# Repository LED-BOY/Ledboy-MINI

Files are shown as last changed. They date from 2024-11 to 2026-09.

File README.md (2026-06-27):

# Ledboy-MINI
Ledboy  mini game console and watch, plus a attiny 416 dev board.

Features: 

-128x32 sd1306 oled screen

-Batt charger IC

-Buzzer

-Sensor

-4k 20mhz MCU

-USB to serial CH340E

-Button input

-Micro USB port

-RGB LED

-RTC clock

-Temp. monitor

-Mosfet controlled batt ouput.




# Ledboy MINI schematics 

[Ledboy mini 1.4 rev b schematic.pdf](https://github.com/user-attachments/files/17895039/Ledboy.mini.1.4.rev.b.schematic.pdf)

# Board Layout

PCB layout

# Assembly guide

[Ledboy mini quick assembly guide.pdf](https://github.com/user-attachments/files/18432793/Ledboy.mini.quick.assembly.guide.pdf)

# How to Flash:

NOTICE:
IF USING ONLY THE USB CABLE WITHOUT A BATTERY, HOW THE CHARGER IC IS CONFIGURED IT ONLY DELIVERS  100MHA, IT IS ENOUGHT FOR FLASHING TURNING ON THE MCU AND THE LED, BUT THE OLED SCREEN WILL NOT WORK PROPERLY.
ADD A BATTERY IF YOU INTEND TO USE THE OLED SCEEN WITH THE DEVICE, OR CHANGE THE R1 RESISTOR VALUE TO A 0603 2K OHM.

## Windows 10/11 tutorial:

*If you have Avrdudess working under linux or Mac, it also should work, CH340E drivers are required.

## Drivers:
Download CH341SER.EXE windows drivers from: https://www.wch-ic.com/products/CH340.html?

## Avrdudess method (recomended):

Download all apps and games precompiled from releases: https://github.com/LED-BOY/Ledboy-MINI/releases

Download Avrdudess: https://github.com/ZakKemble/AVRDUDESS

Make sure all your settings are the same:

The only thing it may be different is your COM port.
If you don't have any other serial device, the only com port available should be your Ledboy 2,
if not, unplug your Ledboy 2 and see what port is missing, then reconnect you Ledboy 2, that is yours Ledboy 2 COM port.
Make sure you select the .hex file in the Flash slot.

Arduboy Flash

## Flash from source:
To Flash from source and make changes to the code you need to install a few things.

1- Legacy arduino software 1.8.19 works well: https://www.arduino.cc/en/software

2- Follow instll instruction to add attiny boards to Arduino IDE: https://github.com/SpenceKonde/megaTinyCore

3- Istall Tiny i2c to librarys, needed to compile: https://github.com/technoblogy/tiny-i2c

Add the new library: tiny-i2c-master.zip

Sin título

Once you have all installed intro the Arduio IDE you can start configuring the board parameters.
Com port should be the one available when you connect your ledboy mini.

DON'T FORGET TO BURN BOOTLOADER BEFORE FLASHING IF USING THIS OPTION.

Arduino flashing

You can check if the program compiles using the check mark, keep in mind that this MCU only has 4096 bytes of flash.

compiling

To upload the program to your Ledboy Mini, click the right arrow.

# Assemble the screen and sensor if needed.
if you are using the lastest watch firmware is configured to have a 1uf capacitor between the sensor pin and GND.
If you dont want to solder the sensor you have to change the variable (constexpr uint8_t sensorSensitivity) to a much higher value like 8.

Ledboy 2 V1 4 REV B v2
You need to use a 4 pin header to solder the oled screen.

Photo for reference.


# Strap options

22mm recommended Hook & Loop Nylon Strap

[https://www.aliexpress.com/item/1005002060362335.html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](https://www.aliexpress.com/item/1005005994868690.html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)

Sin título

# The battery situation

battery

The recommended battery is: 302030 LIPO 3.7v 120mhs, it gives a nice battery duration, it fit nicely, and the batt charger IC is configured to charge at 100mha aprox.
Which is adequate for this battery capacity.

Make sure to be carfull when soldering the battery, do not short the contacts, is better to solder the positive first (red wire), then negative.

## Configure the charger IC

If you whant to add a bigger battery you can change the R1 resistor to a 0603 2k ohm, that will give you the max 500 mha that the charger is capable to deliver.

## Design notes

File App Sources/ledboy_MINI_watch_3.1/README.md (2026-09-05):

# LEDBOY MINI Watch 3.1

Improved ATtiny416 watch firmware. Version 3.0 remains unchanged in its own
folder.

## Reset confirmation

Selecting the reset icon now opens a confirmation screen with the reset icon
and a large number:

- `0` = cancel; do not reset the watch
- `1` = confirm; reset the watch

The screen starts at `0`. Press the button to toggle between `0` and `1`, then
leave it untouched for two seconds to accept the displayed choice. This uses the
same familiar interaction as the watch's other numeric options.

## Additional improvements

- Removed the misleading reset logo and 1.5-second delay shown on every normal
  startup. The watch now starts directly on its normal display.
- A button press used to dismiss a finished minute timer no longer also opens
  the options menu.
- Setting the minute timer to zero now fully resets its counters, LED, and sound
  output instead of only clearing its active flag.
- Added protection against division by zero if the ADC ever returns an invalid
  zero reading.
- Clears a pending RTC tick before re-enabling the RTC interrupt after setting
  the time, preventing an immediate unexpected one-second increment.
- Simplified the battery bar, LED color selector, option positioning, and digit
  drawing to recover enough flash for confirmation and improve maintainability.

## Verified build settings

- Board/core: ATtiny416 with megaTinyCore 2.6.10
- Clock: 5 MHz internal
- millis()/micros(): disabled
- `printf()`: **Default**
- Library: TinyI2C 2.0.1

The `printf: Minimal` setting must not be used for this firmware. The sketch
does not call `printf`, so the default implementation is removed by the linker.
Selecting Minimal forces its approximately 1.1 KB formatter into the image and
overflows the ATtiny416 flash.

Verified default-printf build:

- Flash: 3987 / 4096 bytes (97%)
- Global RAM: 26 / 256 bytes (10%)
- Remaining: 109 bytes flash and 230 bytes RAM for locals/stack

Use the same programmer, UPDI, BOD, and pinout settings as the working 3.0
release.

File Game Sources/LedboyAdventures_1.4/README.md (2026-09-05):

# LedboyAdventures 1.4

Advanced gameplay release for LEDBOY MINI / ATtiny416. Version 1.3 remains
unchanged in its own folder.

## New gameplay

- The dotted grass/ground texture has been removed for a cleaner playfield;
  the trees remain.
- Player, ground-enemy, flying-enemy, shield-orb, and shield-hit movement now
  explicitly erase the previous coordinates so no ghost trails remain.
- Two hazard heights:
  - Ground invaders are avoided with a normal jump and award 2 points.
  - Mirrored flying invaders occupy the middle row, can be cleared by a normal
    jump, and award 3 points.
- Enemy types change during the run instead of following one fixed pattern.
- Respawn positions vary between columns 112 and 119, creating less predictable
  obstacle spacing.
- Shield orbs begin appearing at 12 points and then every 15 points.
- Collecting an orb during a jump awards 5 points and arms a shield.
- The battery-shaped icon at the upper-left indicates an active shield.
- A shield absorbs one collision, resets that hazard, and then disappears.
- Existing progressive difficulty remains: hazards accelerate at scores 20 and
  60, with faster jump animation at the highest tier.
- Current and persistent best-score bars remain on the game-over screen.

## Strategy

Any active jump now clears both ground and flying enemies. Shield orbs still
reward an earlier, higher jump because they travel on the upper row. Saving a
shield lets one mistimed jump continue the run. The score is capped at 117 so
every display write remains inside the OLED.

## Controls

- Press on the title screen to start.
- Press once to jump; release to arm the next jump.
- Shake during gameplay to toggle sound.
- Hold the button for three seconds at power-on to erase the high score.

## Verified build

Compiled with ATtiny416, megaTinyCore 2.6.10, 5 MHz internal clock,
millis/micros disabled, and TinyI2C 2.0.1:

- Version 1.3: 3583 / 4096 bytes flash; 16 / 256 bytes global RAM
- Version 1.4: 3965 / 4096 bytes flash; 15 / 256 bytes global RAM
- Remaining: 131 bytes flash and 241 bytes RAM for locals/stack

Use the same programmer and pinout settings as the working earlier releases.

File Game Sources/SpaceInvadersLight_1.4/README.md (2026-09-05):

# SpaceInvadersLight 1.4

An optimized maintenance release for the LEDBOY MINI / ATtiny416. Version 1.3
is not modified; this directory is a separate Arduino sketch.

## Changes from 1.3

- Fixes the level-20 soft lock. Clearing the final wave now starts a new run.
- Adds a wave-clear score bonus equal to the completed level.
- Replaces the six-byte enemy-death array and nested search with a compact bitmask.
- Makes mothership spawning elapsed-time based, so a missed exact timer value no
  longer prevents it from appearing.
- Makes enemy firing less dependent on exact timer alignment.
- Counts hits on the left edge of enemies, the mothership, and the player.
- Treats erased or corrupt high-score EEPROM data as zero.
- Prevents the boot-time high-score reset from repeatedly writing EEPROM while
  the button remains held.
- Stores the sound/mute preference and avoids writing it when unchanged.
- Uses explicit, overflow-safe battery percentage calculation and guards invalid
  low-voltage operation.
- Keeps the original controls, display layout, pinout, sprites, sleep behavior,
  and gameplay feel.

## Controls

- Tap the button on the intro screen to start.
- Hold the button to move right; release it to move left.
- The ship fires automatically.
- Shake the unit during gameplay to toggle sound.
- Hold the button for four seconds while powering on to clear the high score.

## Arduino build settings

The 1.3 build artifacts identify the original target as an ATtiny416 using
megaTinyCore 2.6.10 at 5 MHz. Keep both TCA0 and TCB0 millis disabled because the
sketch owns TCB0 for its 1 ms game timer. The TinyI2C library is also required.

Recommended settings:

- Board: ATtiny416 (megaTinyCore)
- Clock: 5 MHz
- millis()/micros(): disabled (TCA0 and TCB0)
- Programmer/pinout: same settings used for the working 1.3 build

Compile before flashing and confirm the result remains within the ATtiny416's
4 KB flash limit.

## Verified build

Compiled successfully with megaTinyCore 2.6.10, TinyI2C 2.0.1, ATtiny416,
5 MHz internal clock, and millis/micros disabled:

- Flash: 4080 / 4096 bytes (99%)
- Global RAM: 13 / 256 bytes (5%)

For comparison, the unchanged 1.3 source compiles to 4096 / 4096 bytes and
uses 14 bytes of global RAM with the same toolchain and settings.

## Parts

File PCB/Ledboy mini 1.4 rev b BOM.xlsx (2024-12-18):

*Reference | *Manufacturer Part number | *QTY | *Original | Description | Purchase Link
D1 | DIODE-SCHOTTKY-RB751S40 120mA/40V/370mV SOD-523 | 1 | N |  | link (https://uy.mouser.com/ProductDetail/onsemi-Fairchild/RB751S40?qs=sGAEpiMZZMtbRapU8LlZD+BKBrcrpI38qRYegmS4UMs=)
C1, C2, C6 | 10UF-0603 0603YD106MAT2A | 3 | N |  | link (https://uy.mouser.com/ProductDetail/KYOCERA-AVX/0603YD106MAT2A?qs=+dQmOuGyFcGTGabFXpuZrg==)
C3 | 0.1UF-0603 VJ0603Y823JXXAC | 1 | N |  | link (https://uy.mouser.com/ProductDetail/Vishay-Vitramon/VJ0603Y823JXXAC?qs=TZh2H1ZJFZk6CXb0Y2eXUQ==)
C4, C5 | 22PF-0603 0603YA220JAT2A | 2 | N |  | link (https://uy.mouser.com/ProductDetail/KYOCERA-AVX/0603YA220JAT2A?qs=gEbkM7q0lx9TTxqV7ITXlA==)
R1 | 10KOHM-0603 NTCS0603E3103JLT | 1 | N |  | link (https://uy.mouser.com/ProductDetail/Vishay-BC-Components/NTCS0603E3103JLT?qs=/WiulJ9oly4GqSyQcn8gdg==)
R2, R3, R4, R5 | 100 OHM-0603 ERA-3AED101V | 4 | N |  | link (https://uy.mouser.com/ProductDetail/Panasonic/ERA-3AED101V?qs=MNPzkKEzRtTdzGewEn1kig==)
IC1 | ATTINY416-MNR | 1 | Y |  | link (https://uy.mouser.com/ProductDetail/Microchip-Technology/ATTINY416-MNR?qs=1mbolxNpo8dGl+ZbYkSclA==)
U1 | CH340E_MSOP10 | 1 | Y |  | link (https://www.lcsc.com/product-detail/USB-ICs_WCH-Jiangsu-Qin-Heng-CH340E_C99652.html)
Y1 | CM7VT1A-LowESR-32.768kHz-12.5pF-20-TA-QC | 1 | Y |  | link (https://uy.mouser.com/ProductDetail/Micro-Crystal/CM7VT1A-LowESR-32.768kHz-12.5pF-20-TA-QC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)
S1 | TS04-66-43-BK-100-SMT | 1 | N |  | link (https://uy.mouser.com/ProductDetail/Same-Sky/TS04-66-73-BK-100-SMT?qs=A6eO+MLsxmRAmp3wqRUzZw==)
IC2 | MCP73832T-2DCI/OT | 1 | Y |  | link (https://uy.mouser.com/ProductDetail/Microchip-Technology/MCP73832T-2DCI-OT?qs=yUQqVecv4quyMtCX903Btw==)
LS1 | MLT-7525 or CMT-7525 | 1 | N |  | link (https://www.lcsc.com/product-detail/Buzzers_Jiangsu-Huaneng-Elec-MLT-7525_C95299.html)
x1 | 10118193-0001LF Amphenol FCI | 1 | N |  | link (https://uy.mouser.com/ProductDetail/Amphenol-FCI/10118193-0001LF?qs=Ywefl8B65e63Nsqd+8HZaQ==)
D2 | TJ-S3806SW1TGLCCYRGB-A5 | 1 | N |  | link (https://www.lcsc.com/product-detail/span-style-background-color-ff0-RGB-span-LEDs_TOGIALED-TJ-S3806SW1TGLCCYRGB-A5_C601693.html)
Q1 | 30V 1.3V 250uA P Channel SOT-23 MOSFETs ROHS SI2347DS-T1-BE3 | 1 | N |  | link (https://uy.mouser.com/ProductDetail/Vishay-Siliconix/SI2347DS-T1-BE3?qs=CiayqK2gdcKO20jBryl1OQ==)
oled | I2C SPI de 0,91 128x32 sd1306 | 1 | N | (not assembled) | link (https://es.aliexpress.com/item/1005002197332289.html)
sensor | vibrator sensor | 1 | N | (not assembled) | link (https://es.aliexpress.com/item/1005002033403204.html)
battery | 302030 lipo 3,7v 120mha | 1 | N | (not assembled) | link (https://es.aliexpress.com/item/1005007909515360.html?pdp_npi=4@dis!USD!2.81!1.94!!!20.30!14.01%)

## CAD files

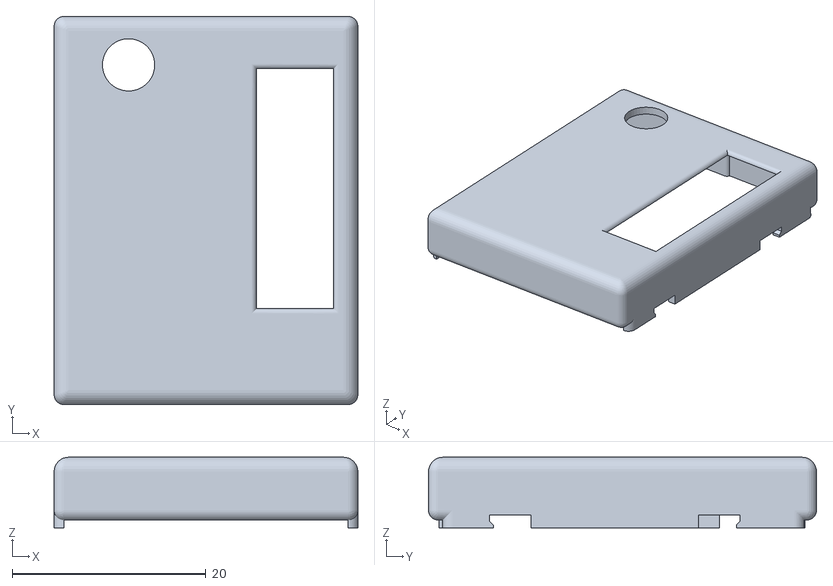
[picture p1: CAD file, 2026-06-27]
stl files/top.stl
31.4 x 40.1 x 7.30

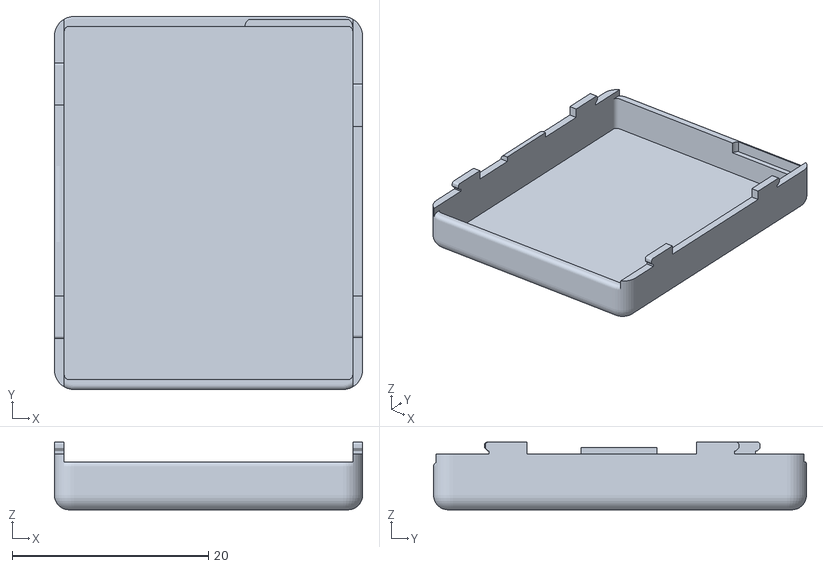
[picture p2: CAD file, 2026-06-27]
stl files/bottom.stl
31.4 x 38.0 x 6.90

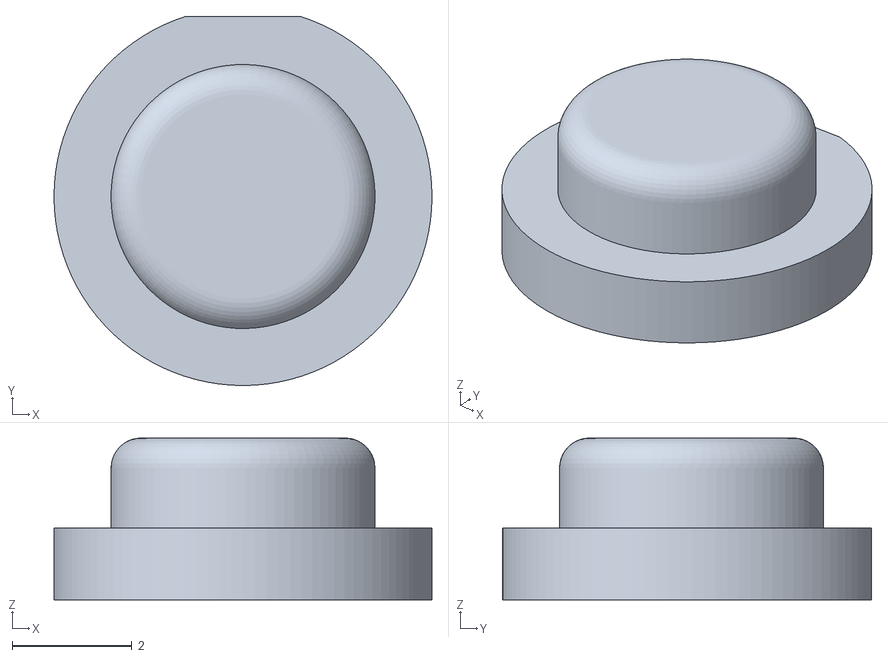
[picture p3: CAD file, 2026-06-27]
stl files/button.stl
6.30 x 6.15 x 2.70

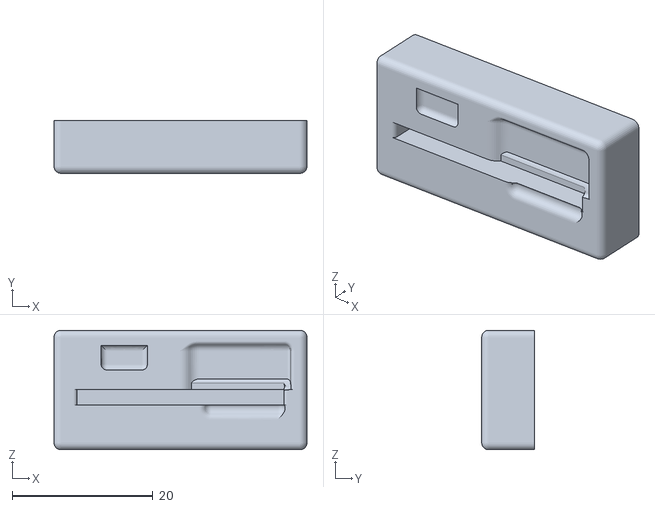
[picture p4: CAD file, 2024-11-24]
stl files/base.stl
36.0 x 7.50 x 17.0

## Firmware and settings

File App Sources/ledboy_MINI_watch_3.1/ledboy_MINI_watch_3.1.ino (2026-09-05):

/*
  LEDBOY MINI Watch 3.1 for ATtiny series 1.
  Flash CPU Speed: 5MHz.
  This code is released under GPL v3.
*/

#include "tinyOLED.h"
#include "sprites.h"
#include "digits.h"
#include "MinuteTimer.h"

#include <util/delay.h>
#include <avr/interrupt.h>
#include <avr/sleep.h>

// =====================================================
// CONSTANTS
// =====================================================

// Battery
constexpr uint16_t MAX_VOLTAGE = 4100u;
constexpr uint16_t MIN_VOLTAGE = 3100u;
constexpr uint8_t LOW_BATT = 140;

// CPU / Timer
constexpr uint32_t CPU_FREQ = 5000000UL;
constexpr uint16_t TCA_PRESCALER = 64;
constexpr uint16_t TCA_PER_VALUE =
  ((CPU_FREQ / TCA_PRESCALER) / 1000) - 1;

// Modes
constexpr uint8_t STANDBY = 0;
constexpr uint8_t ON = 1;
constexpr uint8_t IDLE = 2;

// Sensor
constexpr uint8_t sensorSensitivity = 3;

// Options
constexpr uint8_t OPTION_COUNT = 5;
constexpr uint8_t RESET_CANCEL = 0;
constexpr uint8_t RESET_CONFIRM = 1;

// =====================================================
// HARDWARE HELPERS
// =====================================================

inline void oledPowerOff() __attribute__((always_inline));
inline void oledPowerOn() __attribute__((always_inline));
inline bool buttonLow() __attribute__((always_inline));
inline bool buttonHigh() __attribute__((always_inline));
inline bool batteryCharging() __attribute__((always_inline));

inline void oledPowerOff() {
  PORTC.OUTSET = PIN0_bm;
}

inline void oledPowerOn() {
  PORTC.OUTCLR = PIN0_bm;
}

inline bool buttonLow() {
  return !(PORTC.IN & PIN3_bm);
}

inline bool buttonHigh() {
  return PORTC.IN & PIN3_bm;
}

inline bool batteryCharging() {
  return !(PORTA.IN & PIN4_bm);
}

// =====================================================
// GLOBAL VARIABLES
// =====================================================

bool needsOnRefresh = true;
uint8_t ledColor = 0;
uint8_t lastSecond = 255;

uint16_t timer = 0;
uint16_t optionsDebounce = 800;

bool awake = false;

volatile bool shouldWakeUp = true;

volatile uint8_t seconds = 0;
volatile uint8_t minutes = 0;
volatile uint8_t hours = 0;
volatile uint8_t mode = ON;

volatile uint8_t interruptDebounce = 0;
volatile uint8_t interruptSensitivity = 0;
volatile uint16_t interruptTimer = 0;

// =====================================================
// FUNCTION PROTOTYPES
// =====================================================

void setup();
void loop();

void initTCA();

void displayTime(uint8_t hourPos,
                 uint8_t minutesPos);

void displayBatt();
void displayMode();

void ledON(bool optionSelected);

void wakeUpFromSleep();

void options();

uint8_t setNumber(uint8_t sprite,
                  uint8_t stepSize,
                  uint8_t limit);

void setTime();

void drawTime(uint8_t firstPixel,
              uint8_t value);

inline bool buttonDebounce(uint16_t debounceDelay);

void goToSleep();

uint16_t readSupplyVoltage();

// =====================================================
// INTERRUPTS
// =====================================================

ISR(PORTA_PORT_vect);
ISR(PORTC_PORT_vect);
ISR(TCA0_OVF_vect);
ISR(TCB0_INT_vect);
ISR(RTC_PIT_vect);

// =====================================================
// SETUP
// =====================================================

void setup() {

  // Configure Ports
  PORTA.DIR = 0b00000000;
  PORTB.DIR = 0b00000011;
  oledPowerOff();
  PORTC.DIR = 0b00000011;

  // Pullups / Interrupts
  PORTC.PIN2CTRL = PORT_PULLUPEN_bm;

  PORTA.PIN4CTRL =
    PORT_PULLUPEN_bm | PORT_ISC_BOTHEDGES_gc;

  PORTC.PIN3CTRL =
    PORT_PULLUPEN_bm | PORT_ISC_BOTHEDGES_gc;

  // RTC Setup
  CCP = 0xD8;

  CLKCTRL.XOSC32KCTRLA =
    CLKCTRL_ENABLE_bm;

  while (RTC.STATUS > 0)
    ;

  RTC.CTRLA =
    RTC_PRESCALER_DIV1_gc | RTC_RUNSTDBY_bm;

  RTC.CLKSEL =
    RTC_CLKSEL_TOSC32K_gc;

  while (RTC.PITSTATUS > 0)
    ;

  RTC.PITCTRLA =
    RTC_PERIOD_CYC32768_gc | RTC_PITEN_bm;

  RTC.PITINTCTRL =
    RTC_PI_bm;

  initTCA();

  sei();

  set_sleep_mode(SLEEP_MODE_PWR_DOWN);

  // OLED init
  wakeUpFromSleep();
}

// =====================================================
// MAIN LOOP
// =====================================================

void loop() {

  wakeUpFromSleep();

  displayMode();

  // If minute timer finished,
  if (minuteTimer.isFinished() && minuteTimer.isActive() && buttonLow()) {

    minuteTimer.reset();
    oled.begin();
    oled.clearScreen();
    needsOnRefresh = true;
    timer = interruptTimer;
    optionsDebounce = 800;
    return;  // do not let the same press immediately open the options menu
  }

  // Button
  if (buttonDebounce(optionsDebounce)) {

    optionsDebounce = 50;

    if (readSupplyVoltage() > MIN_VOLTAGE) {
      options();
    }
  }

  // Auto sleep
  const uint16_t elapsed =
    (uint16_t)(interruptTimer - timer);

  if (elapsed > 4000) {

    timer = interruptTimer;

    optionsDebounce = 800;

    needsOnRefresh = true;

    oled.clearScreen();

    goToSleep();
  }
}

// =====================================================
// INIT TCA
// =====================================================

void initTCA() {

  TCA0.SINGLE.CTRLB =
    TCA_SINGLE_WGMODE_NORMAL_gc;

  TCA0.SINGLE.PER =
    TCA_PER_VALUE;

  TCA0.SINGLE.INTCTRL =
    TCA_SINGLE_OVF_bm;

  TCA0.SINGLE.CTRLA =
    TCA_SINGLE_CLKSEL_DIV64_gc | TCA_SINGLE_ENABLE_bm;

  timer = interruptTimer;
}

// =====================================================
// DISPLAY MODE
// =====================================================

void displayMode() {

  if (!awake) return;

  const uint8_t currentMode = mode;
  const uint8_t currentSecond = seconds;

  // Mode changed
  if (currentMode == ON && needsOnRefresh) {

    oled.brightScreen();

    displayBatt();

    needsOnRefresh = false;

    ledColor = 0;

    PORTA.DIRCLR =
      RED_LED_PIN | GREEN_LED_PIN | BLUE_LED_PIN;

  } else if (currentMode == STANDBY) {

    oled.dimScreen();
  }

  // Update only if needed
  if (currentMode != IDLE || currentSecond != lastSecond) {

    lastSecond = currentSecond;

    mode = IDLE;

    const bool timerActive =
      minuteTimer.isActive();

    const bool timerFinished =
      minuteTimer.isFinished();

    if (timerActive && timerFinished) {

      oled.sleep();

      return;
    }

    displayTime(64, 0);

    if (timerActive && !timerFinished) {

      const uint32_t target =
        minuteTimer.targetSeconds;

      if (target) {

        const uint32_t remaining =
          target - minuteTimer.elapsedSeconds;

        const uint8_t timerLine =
          ((uint32_t)remaining * 127u) / target;

        oled.drawLine(
          0,
          0,
          timerLine,
          0b00000101);
      }
    }
  }
}

inline void displayTime(uint8_t hourPos,
                        uint8_t minutesPos) {

  drawTime(hourPos, hours);
  drawTime(minutesPos, minutes);

  _PROTECTED_WRITE(WDT.CTRLA, 0);
}

// =====================================================
// DISPLAY BATTERY
// =====================================================

void displayBatt() {

  uint16_t actualVoltage =
    constrain(readSupplyVoltage(),
              MIN_VOLTAGE,
              MAX_VOLTAGE);

  actualVoltage -= MIN_VOLTAGE;

  actualVoltage =
    ((uint32_t)actualVoltage * 117u) / (MAX_VOLTAGE - MIN_VOLTAGE);

  oled.drawLine(
    10,
    3,
    actualVoltage,
    0b11100000);

  oled.drawSprite(
    0,
    3,
    batteryCharging()
      ? chargingSprite
      : battSprite,
    8,
    1,
    false);
}

// =====================================================
// LED CONTROL
// =====================================================

void ledON(bool optionSelected) {

  while ((uint16_t)(interruptTimer - timer) < 2000) {

    if (buttonDebounce(50) || optionSelected) {

      optionSelected = false;

      ledColor++;

      if (ledColor > 3) {
        ledColor = 0;
      }

      PORTA.DIRCLR =
        RED_LED_PIN | GREEN_LED_PIN | BLUE_LED_PIN;

      PORTA.OUTSET =
        RED_LED_PIN | GREEN_LED_PIN | BLUE_LED_PIN;

      if (ledColor) {
        const uint8_t selectedPin =
          ledColor == 1 ? RED_LED_PIN :
          ledColor == 2 ? GREEN_LED_PIN : BLUE_LED_PIN;

        PORTA.OUTCLR = selectedPin;
        PORTA.DIRSET = selectedPin;
      }
    }
  }
}

// =====================================================
// WAKEUP
// =====================================================

void wakeUpFromSleep() {

  if (!shouldWakeUp || awake) {
    return;
  }

  sleep_disable();

  initTCA();

  oledPowerOn();
  _delay_ms(150);

  // Restore I2C
  PORTB.DIRCLR =
    PIN0_bm | PIN1_bm;

  PORTB.PIN0CTRL =
    PORT_PULLUPEN_bm;

  PORTB.PIN1CTRL =
    PORT_PULLUPEN_bm;

  _delay_us(100);

  oled.begin();
  oled.clearScreen();

  awake = true;
}

// =====================================================
// OPTIONS
// =====================================================

void options() {

  uint8_t option = 0;

  oled.clearScreen();

  for (uint8_t x = 0;
       x < OPTION_COUNT;
       x++) {

    oled.drawSprite(
      102 - (22 * x),
      1,
      optionSprites[x],
      16,
      2,
      false);
  }

  while (true) {

    if (buttonDebounce(25) || option == 0) {

      if (option >= OPTION_COUNT) {
        break;
      }

      oled.drawLine(
        0,
        0,
        127,
        0x00);

      oled.drawSprite(
        102 - (22 * option),
        0,
        arrow,
        8,
        1,
        true);

      option++;

      if (option > OPTION_COUNT) {
        break;
      }
    }

    if ((uint16_t)(interruptTimer - timer) > 2000) {

      timer = interruptTimer;

      switch (option) {

        case 1:
          ledON(true);
          break;

        case 2:
          minuteTimer.setMinutes(
            setNumber(1, 5, 65));
          break;

        case 3:
          setTime();
          break;

        case 4:
          interruptSensitivity =
            setNumber(3, 1, 2) * sensorSensitivity;
          break;

        case 5:
          // Explicit confirmation: 0 cancels, 1 resets the watch.
          if (setNumber(4, 1, 2) == RESET_CONFIRM) {
            _PROTECTED_WRITE(
              RSTCTRL.SWRR,
              1);
          }
          break;
      }

      break;
    }
  }

  oled.clearScreen();
}

// =====================================================
// SET NUMBER
// =====================================================

uint8_t setNumber(uint8_t spriteIndex,
                  uint8_t stepSize,
                  uint8_t limit) {

  uint8_t value = 0;

  oled.clearScreen();

  oled.drawSprite(
    90,
    1,
    optionSprites[spriteIndex],
    16,
    2,
    false);

  drawTime(0, value);

  while (true) {

    if (buttonDebounce(50)) {

      value += stepSize;

      if (value >= limit) {
        value = 0;
      }

      drawTime(0, value);
    }

    if ((uint16_t)(interruptTimer - timer) > 2000) {
      break;
    }
  }

  return value;
}

// =====================================================
// SET TIME
// =====================================================

void setTime() {

  RTC.PITINTCTRL = 0;

  uint8_t arrowPos = 86;

  for (uint8_t x = 0; x < 3; x++) {

    oled.clearScreen();

    oled.drawSprite(
      arrowPos,
      0,
      arrow,
      8,
      1,
      true);

    arrowPos = 22;

    if (x < 2) {
      displayTime(64, 0);
    } else {
      drawTime(0, seconds);
    }

    while (true) {

      if ((uint16_t)(interruptTimer - timer) > 285 && buttonLow()) {

        timer = interruptTimer;

        switch (x) {

          case 0:
            if (++hours > 23) {
              hours = 0;
            }
            break;

          case 1:
            if (++minutes > 59) {
              minutes = 0;
            }
            break;

          case 2:
            if (++seconds > 59) {
              seconds = 0;
            }
            break;
        }

        drawTime(
          (x == 0 ? 64 : 0),
          (x == 0
             ? hours
             : (x == 1
                  ? minutes
                  : seconds)));
      }

      if ((uint16_t)(interruptTimer - timer) > 2500) {

        timer = interruptTimer;
        break;
      }
    }
  }

  RTC.PITINTFLAGS =
    RTC_PI_bm;
  RTC.PITINTCTRL =
    RTC_PI_bm;
}

// =====================================================
// DRAW TIME
// =====================================================

void drawTime(uint8_t firstPixel,
              uint8_t value) {

  const uint8_t units = value % 10;
  const uint8_t tens = value / 10;

  if (value < 10) {

    if (firstPixel == 64) {

      oled.drawLine(96, 1, 32, 0x00);
      oled.drawLine(96, 2, 32, 0x00);

    } else {

      oled.drawSprite(
        firstPixel + 32,
        1,
        numbers[0],
        14,
        2,
        true);
    }

  } else {

    oled.drawSprite(
      firstPixel + 32,
      1,
      numbers[tens],
      14,
      2,
      true);
  }

  oled.drawSprite(
    firstPixel,
    1,
    numbers[units],
    14,
    2,
    true);
}

// =====================================================
// BUTTON DEBOUNCE
// =====================================================

inline bool buttonDebounce(uint16_t debounceDelay) {

  static bool state = true;
  static uint16_t lastChange = 0;

  const bool reading = buttonHigh();

  // No change
  if (reading == state) {

    lastChange = interruptTimer;
    return false;
  }

  // Debounce time
  if ((uint16_t)(interruptTimer - lastChange)
      <= debounceDelay) {

    return false;
  }

  // Update state
  lastChange = interruptTimer;
  state = reading;

  // Button pressed
  if (!reading) {
    timer = interruptTimer;
    return true;
  }

  return false;
}

// =====================================================
// SLEEP
// =====================================================

void goToSleep() {

  const bool charging =
    batteryCharging();

  if (!charging && (readSupplyVoltage() > (MIN_VOLTAGE + LOW_BATT))) {

    PORTC.PIN2CTRL =
      (PORTC.PIN2CTRL & ~PORT_ISC_gm) | (interruptSensitivity ? PORT_ISC_RISING_gc : PORT_ISC_INTDISABLE_gc);

  } else if (charging) {

    oled.drawSprite(
      0,
      3,
      chargingSprite,
      8,
      1,
      false);
  }

  if (!charging) {
    oled.sleep();

    PORTB.DIRCLR =
      PIN0_bm | PIN1_bm;

    PORTB.PIN0CTRL &=
      ~PORT_PULLUPEN_bm;

    PORTB.PIN1CTRL &=
      ~PORT_PULLUPEN_bm;

    oledPowerOff();
  }

  ADC0.CTRLA = 0;

  TCA0.SINGLE.CTRLA = 0;

  RSTCTRL.RSTFR =
    RSTCTRL_PORF_bm;

  awake = false;

  shouldWakeUp = false;

  sleep_enable();

  sleep_cpu();
}

// =====================================================
// READ VCC
// =====================================================

uint16_t readSupplyVoltage() {

  ADC0.CTRLA = ADC_ENABLE_bm;

  VREF.CTRLA = VREF_ADC0REFSEL_1V5_gc;

  ADC0.MUXPOS = ADC_MUXPOS_INTREF_gc;

  ADC0.COMMAND = ADC_STCONV_bm;

  while (!(ADC0.INTFLAGS & ADC_RESRDY_bm))
    ;

  ADC0.INTFLAGS = ADC_RESRDY_bm;

  const uint16_t reading = ADC0.RES;

  ADC0.CTRLA = 0;

  if (!reading) return 0;
  return 1534500UL / reading;
}

// =====================================================
// TCA INTERRUPT
// =====================================================

ISR(TCA0_OVF_vect) {

  interruptTimer++;

  TCA0.SINGLE.INTFLAGS =
    TCA_SINGLE_OVF_bm;
}

// =====================================================
// PORTA INTERRUPT
// =====================================================

ISR(PORTA_PORT_vect) {

  const uint8_t flags =
    PORTA.INTFLAGS;

  PORTA.INTFLAGS = flags;

  if (flags & PIN4_bm) {

    _PROTECTED_WRITE(
      WDT.CTRLA,
      WDT_PERIOD_4KCLK_gc);
  }

  if (mode != ON) {
    mode = ON;
  }

  if (!shouldWakeUp) {

    PORTC.PIN2CTRL &=
      ~PORT_ISC_gm;

    shouldWakeUp = true;
  }
}

// =====================================================
// PORTC INTERRUPT
// =====================================================

ISR(PORTC_PORT_vect) {

  const uint8_t flags =
    PORTC.INTFLAGS;

  PORTC.INTFLAGS = flags;

  if (flags & PIN2_bm) {

    interruptDebounce++;

    if (interruptDebounce > interruptSensitivity) {

      PORTC.PIN2CTRL &=
        ~PORT_ISC_gm;

      interruptDebounce = 0;

      mode = STANDBY;

      shouldWakeUp = true;

    } else {

      sleep_cpu();
    }
  }

  if (flags & PIN3_bm) {

    if (mode != ON) {
      mode = ON;
    }

    if (!shouldWakeUp) {

      PORTC.PIN2CTRL &=
        ~PORT_ISC_gm;

      shouldWakeUp = true;
    }
  }
}

// =====================================================
// RTC INTERRUPT
// =====================================================

ISR(RTC_PIT_vect) {

  RTC.PITINTFLAGS =
    RTC_PI_bm;

  interruptDebounce = 0;

  uint8_t s = seconds + 1;

  if (s > 59) {

    s = 0;

    uint8_t m = minutes + 1;

    if (m > 59) {

      m = 0;

      uint8_t h = hours + 1;

      if (h > 23) {
        h = 0;
      }

      hours = h;
    }

    minutes = m;
  }

  seconds = s;

  minuteTimer.tick();

  if (!shouldWakeUp) {
    sleep_cpu();
  }
}

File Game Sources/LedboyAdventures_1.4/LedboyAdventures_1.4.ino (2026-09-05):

/* LedboyAdventures 1.4 for LEDBOY MINI and compatible ATtiny 0/1/2 series.
  Flash CPU Speed 5MHz.
  this code is released under GPL v3, you are free to use and modify.
  released on 2022.

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
    To contact us: ledboy.net
    ledboyconsole@gmail.com
*/
#include "tinyOLED.h"
#include "sprites.h"
#include <avr/interrupt.h>
#include <avr/sleep.h>
#include <avr/eeprom.h>

#if defined(MILLIS_USE_TIMERA0) || defined(MILLIS_USE_TIMERB0)
#error "This sketch does't use TCA0 nor TCB0 to save flash, select Disabled."
#endif

#define SCREEN_ON PORTC.OUT &= ~PIN0_bm;  // P CHANNEL mosfet low to activate
#define SCREEN_OFF PORTC.OUT |= PIN0_bm;  // P CHANNEL mosfet high to deactivate
#define BUTTONLOW !(PORTC.IN & PIN3_bm)   // button press low
#define BUTTONHIGH (PORTC.IN & PIN3_bm)   // button not pressed high
#define MAXVOLTAGE 4100                   // max voltage allowed to the battery
#define MINVOLTAGE 3200                   // min voltage allowed to be operational
#define BATTCHR !(PORTA.IN & PIN4_bm)     // battery charging
#define EEPROM_SCORE 126
#define ENEMY_COUNT 3
#define MAX_SCORE 117

uint8_t bitShift1 = 8;
uint8_t bitShift2 = 0;
uint8_t jumpLength = 19;
uint16_t timer = 0;
uint16_t timer2 = 0;
uint16_t timer3 = 0;
volatile uint8_t  frameCounter = 0;
volatile uint8_t interruptDebounce = 0;
volatile uint16_t interruptTimer = 0;
volatile bool sound = true;


void setup() {
  PORTA.DIR = 0b00000000;                   // setup ports in and out //  pin2 (GREEN) on
  PORTB.DIR = 0b00000011;                   // setup ports in and out
  PORTC.DIR = 0b00000011;                   // setup ports in and out
  PORTC.PIN3CTRL = PORT_PULLUPEN_bm;        // button pullup
  PORTC.PIN2CTRL = PORT_PULLUPEN_bm;        // sensor pullup
  PORTA.PIN4CTRL = PORT_PULLUPEN_bm;        // charge pin pullup
  PORTA.PIN4CTRL |= PORT_ISC_BOTHEDGES_gc;  //attach interrupt to portA pin 4 keeps pull up enabled

  TCB0.CCMP = 5000;                  // Set compare value for 1ms (5 MHz clock)
  TCB0.CTRLA = TCB_CLKSEL_CLKDIV1_gc | TCB_ENABLE_bm; // Enable TCB0 with no prescaler
  TCB0.INTCTRL = TCB_CAPT_bm;        // Enable interrupt

  sei();                                             // enable interrupts
  set_sleep_mode(SLEEP_MODE_PWR_DOWN);               // configure sleep mode
  _PROTECTED_WRITE(WDT.CTRLA, WDT_PERIOD_4KCLK_gc);  // enable watchdog 4 sec. aprox.

  // Hold the button during power-up for three seconds to clear the high score.
  while (BUTTONLOW || interruptTimer < 300) {
    if (interruptTimer > 3000) {  // clear HI score before the 4-second watchdog
      writeScoreToEEPROM(EEPROM_SCORE, 0);
      while (BUTTONLOW);
      break;  // never wear EEPROM by writing repeatedly while held
    }
  }
  oled.begin();  // start oled screen
  oled.clearScreen();
  _PROTECTED_WRITE(WDT.CTRLA, 0);  // disable watchdog

  if (BATTCHR) {
    drawSprite(4, 0, battIcon, 0);
    goToSleep();
  }
}

void loop() {
  oled.clearScreen();// screen clear
  intro();
  oled.clearScreen();
  game();
}

// Main game function
void game() {
  uint8_t playerXPos = 16;
  uint8_t playerYPos = 2;
  uint8_t enemiesPos[ENEMY_COUNT] = {46, 80, 120};
  uint8_t score = 0;
  uint8_t backgroundXPos = 0;
  uint8_t flyingEnemies = 0;
  uint8_t bonusXPos = 255;
  uint8_t nextBonus = 12;
  const uint8_t skyElementsPos[8] = {0, 7, 10, 17, 31, 37, 60, 66};
  bool birdState = false;
  bool jump = false;
  bool jumpReady = true;
  bool shield = false;
  bool soundStatus = sound;

  // Wait for button press to start the game
  while (BUTTONLOW);
  timer = timer2 = timer3 = interruptTimer;
  PORTC.PIN2CTRL |= PORT_ISC_RISING_gc;

  // Main game loop
  while (true) {
    if (soundStatus != sound) {
      soundStatus = sound;
      PORTC.PIN2CTRL |= PORT_ISC_RISING_gc;
    }

    // Update game state every 50 milliseconds
    if ((interruptTimer - timer) > 50) {
      timer = interruptTimer;
      uint8_t enemyStep = 1 + (score >= 20) + (score >= 60);

      // Update enemy positions
      for (uint8_t x = 0; x < ENEMY_COUNT; x++) {
        if (enemiesPos[x] <= 120) {
          oled.drawLine(enemiesPos[x], 2, 8, 0x00);
          oled.drawLine(enemiesPos[x], 3, 8, 0x00);
        }
        if (enemiesPos[x] <= enemyStep || enemiesPos[x] > 200) {
          if (enemiesPos[x] <= enemyStep) {
            uint8_t points = (flyingEnemies & _BV(x)) ? 3 : 2;
            score = min((uint8_t)MAX_SCORE, (uint8_t)(score + points));
          }
          enemiesPos[x] = 112 + ((interruptTimer + x) & 0x07);
          if (((score >> 1) + x) & 0x02) flyingEnemies |= _BV(x);
          else flyingEnemies &= ~_BV(x);
        } else {
          enemiesPos[x] -= enemyStep; // Progressive difficulty as score rises
          jumpLength = score >= 60 ? 13 : 19;
        }
      }

      // Shield bonuses enter play at score milestones and travel with the world.
      if (bonusXPos <= 120) {
        oled.drawLine(bonusXPos, 1, 8, 0x00);
        if (bonusXPos <= enemyStep) bonusXPos = 255;
        else bonusXPos -= enemyStep;
      } else if (score >= nextBonus) {
        bonusXPos = 120;
        nextBonus += 15;
      }

      // Update player position during jump
      if (playerYPos < 2) {
        clearPlayerTrail(playerXPos);
        playerXPos++;
      } else if (playerXPos > 16 && playerYPos == 2) {
        clearPlayerTrail(playerXPos);
        playerXPos--;
      }

      // Draw the trees; the dotted grass/ground texture is intentionally absent.
      for (uint8_t x = 0; x < 127; x += 8) {
        bool outsidePlayer = (x + 7 < playerXPos) || (x > playerXPos + 7);
        if (outsidePlayer || playerYPos > 1) {
          drawSprite(x, 1, trees, false);
        }
      }
    }

    // Update background every 100 milliseconds
    if ((interruptTimer - timer2) > 100) {
      timer2 = interruptTimer;
      oled.drawLine(0, 0, 127, 0x00); // Clear sky

      // Scroll background
      backgroundXPos = (backgroundXPos - 2) & 0x7F;

      // Draw sky elements
      bool cloudState = false;
      for (uint8_t x = 0; x < 8; x++) {
        cloudState = !cloudState;
        drawSprite((backgroundXPos + skyElementsPos[x]) & 0x7F, 0, cloud, cloudState);
      }
      drawSprite((backgroundXPos + 48) & 0x7F, 0, bird, birdState);
      drawSprite((backgroundXPos + 90) & 0x7F, 0, bird, birdState);
      if (shield) drawSprite(2, 0, battIcon, false);
    }

    // Handle player jump
    if (BUTTONHIGH) jumpReady = true;
    if (BUTTONLOW && jumpReady && playerYPos == 2) {
      jumpReady = false;
      jump = true;
      playerYPos = 1;
      beep(250, 25);
    }

    // Update player position during jump
    if (playerYPos != 2) {
      if (bitShiftLedBoySprite(playerXPos, playerYPos, jump)) {
        if (playerYPos == 1 && jump) {
          playerYPos = 0;
        } else {
          jump = false;
          playerYPos++;
        }
      }
    }
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

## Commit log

2024-12-03 Create print settings
2024-12-18 Rename Ledboy 2 1.4 rev b BOM.xlsx to Ledboy mini 1.4 rev b BOM.xlsx
    [Ledboy mini 1.4 rev b BOM.xlsx]
2026-09-05 Add files via upload
    Reset confirmation now works as requested:
    - 0 — cancel, no reset
    - 1 — reset the watch
    It defaults to 0. Press to switch between 0 and 1, then wait two seconds to confirm.
    Additional improvements include safer ADC readings, corrected RTC interrupt handling, cleaner timer dismissal, complete timer reset at zero, faster startup, and smaller display/LED routines.
    [MinuteTimer.cpp, MinuteTimer.h, ledboy_MINI_watch_3.1.ino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]

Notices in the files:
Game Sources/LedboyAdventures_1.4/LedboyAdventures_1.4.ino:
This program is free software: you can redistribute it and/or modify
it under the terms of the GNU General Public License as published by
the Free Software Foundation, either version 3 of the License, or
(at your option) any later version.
